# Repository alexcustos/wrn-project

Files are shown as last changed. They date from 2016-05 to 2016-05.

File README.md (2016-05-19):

# WRN Project

WRN is 3-in-1 device for RS232 serial port was designed to solve some standard problems of a home server.

## The board based on the ATmega328P and consist of:

* The hardware watchdog timer
* True random number generator (based on avalanche noise)
* Low power 2.4GHz transceiver (nRF24L01+)

## The project consist of the following components:

* The schematic and the PCB (KiCAD project)
* The firmware (AtmelStudio project)
* Linux daemon, watchdog driver and the installation for the Gentoo (Makefile)

The project depends on:
* [alexcustos/RF24](https://github.com/alexcustos/RF24)
* [alexcustos/RF24Network](https://github.com/alexcustos/RF24Network)

Here's an article in russian with more details:
* [Part 1](https://geektimes.ru/post/275912/)
* [Part 2](https://habrahabr.ru/post/300968/)

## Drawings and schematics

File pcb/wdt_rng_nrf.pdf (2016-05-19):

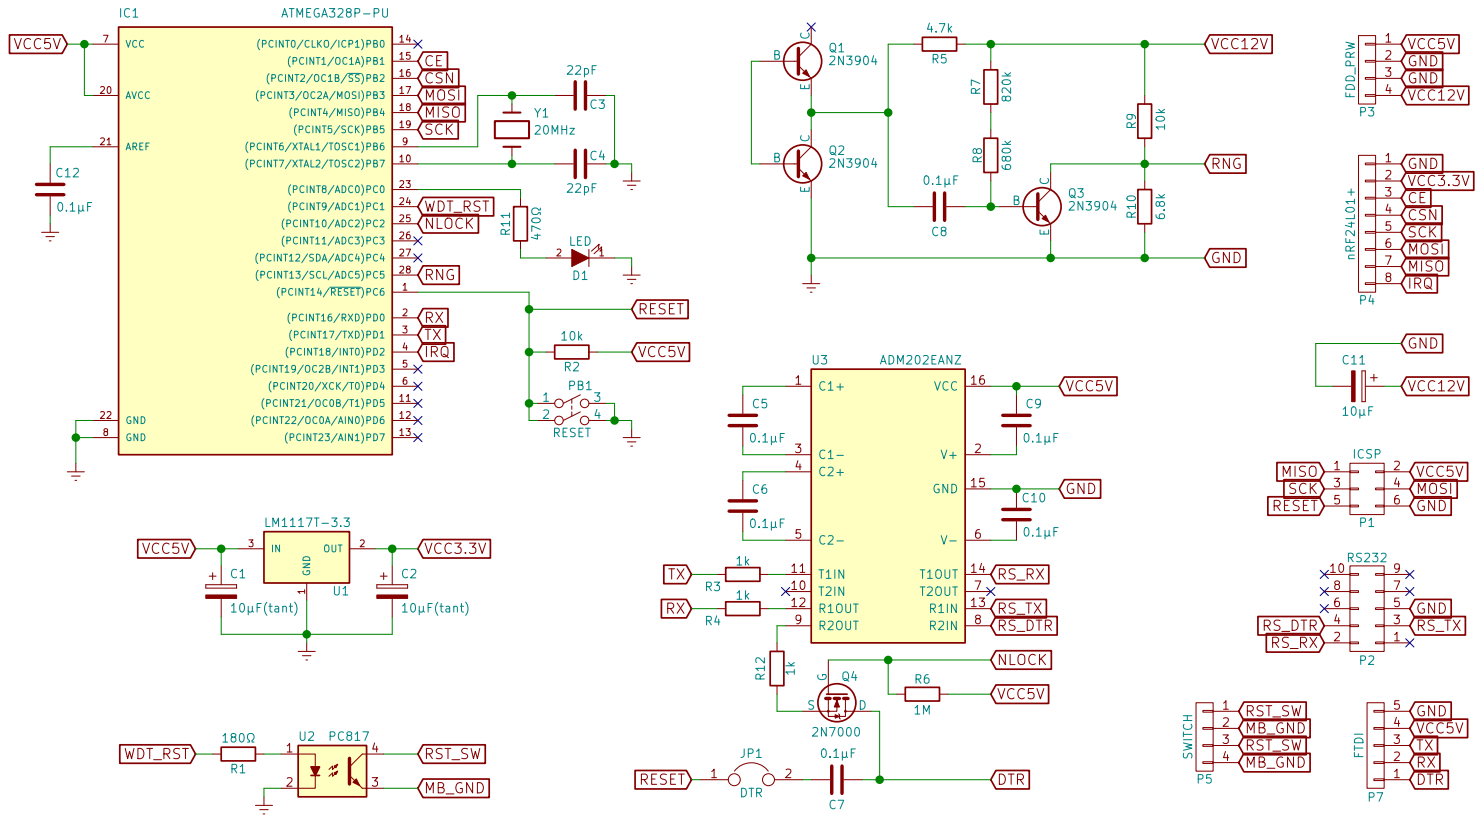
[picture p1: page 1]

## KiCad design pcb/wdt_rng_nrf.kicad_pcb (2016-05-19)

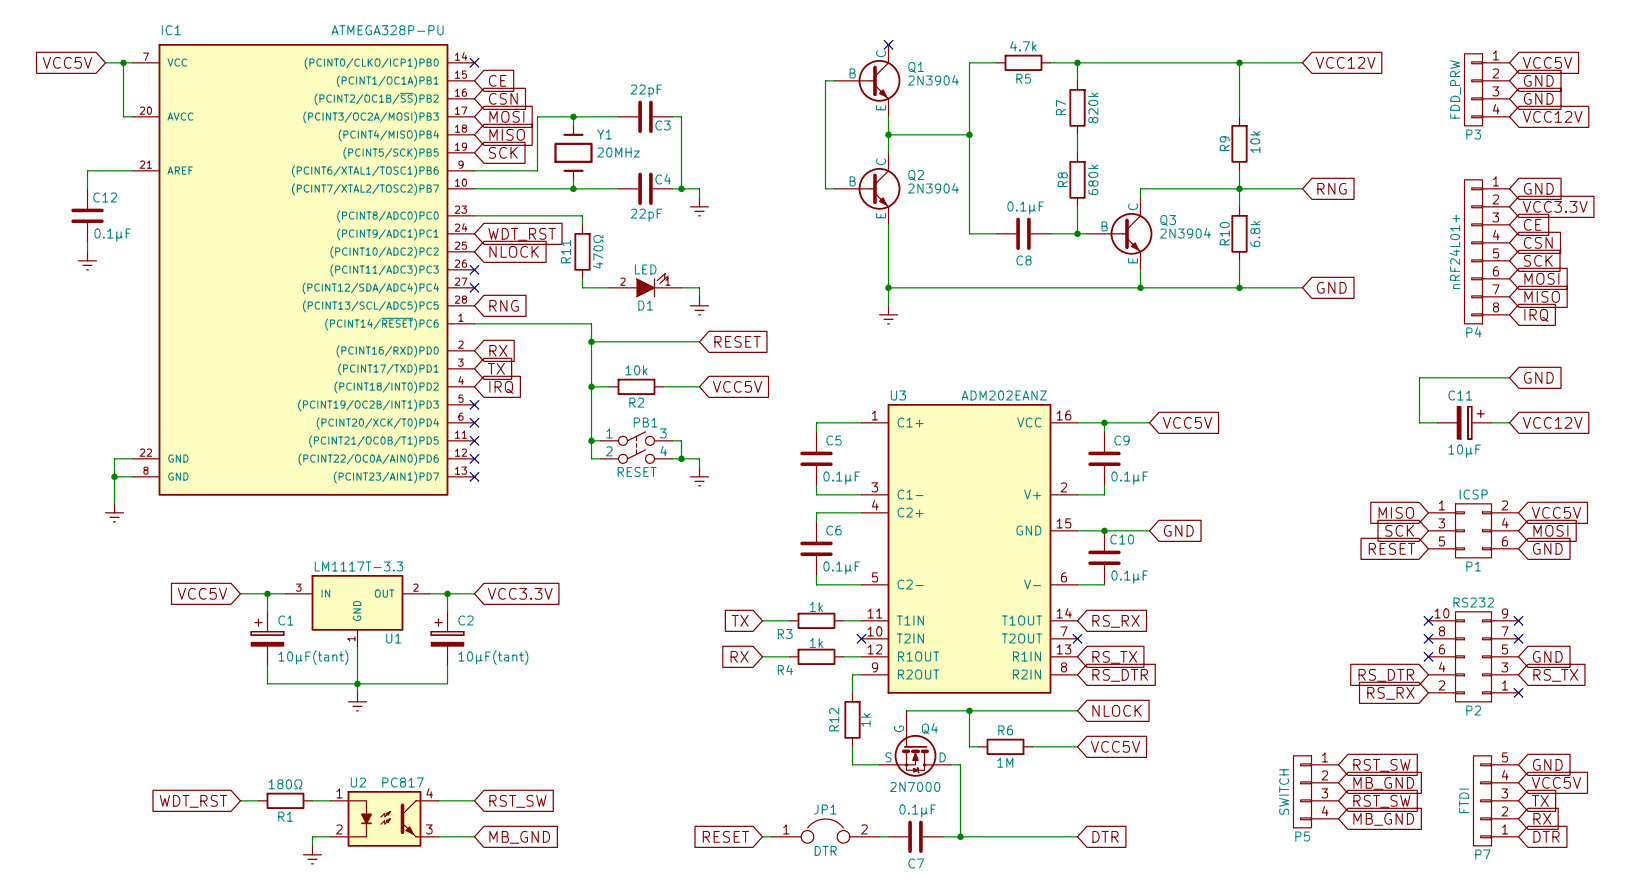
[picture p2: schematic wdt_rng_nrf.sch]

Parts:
C1, C2: 10μF(tant); C_Disc_D7.5_P5
C3, C4: 22pF; C_Disc_D3_P2.5
C5, C6, C7, C8, C9, C10, C12: 0.1μF; C_Disc_D7.5_P5
C11: 10μF; C_Radial_D5_L6_P2.5
D1: LED; LED-5MM
IC1: ATMEGA328P-PU; DIP-28_W7.62mm
JP1: DTR; Pin_Header_Straight_1x02
P1: ICSP; Pin_Header_Straight_2x03
P2: RS232; Pin_Header_Straight_2x05
P3: FDD_PRW; Pin_Header_Angled_1x04
P4: nRF24L01+; Pin_Header_Angled_1x08
P5: SWITCH; Pin_Header_Angled_1x04
P7: FTDI; Pin_Header_Straight_1x05
PB1: RESET; Push_E-Switch_TC-0102
Q1, Q2, Q3: 2N3904; TO-92_2N3904
Q4: 2N7000; TO-92_2N7000
R1: 180Ω; Resistor_Horizontal_RM10mm
R2, R9: 10k; Resistor_Horizontal_RM10mm
R3, R4, R12: 1k; Resistor_Horizontal_RM10mm
R5: 4.7k; Resistor_Horizontal_RM10mm
R6: 1M; Resistor_Horizontal_RM10mm
R7: 820k; Resistor_Horizontal_RM10mm
R8: 680k; Resistor_Horizontal_RM10mm
R10: 6.8k; Resistor_Horizontal_RM10mm
R11: 470Ω; Resistor_Horizontal_RM10mm
U1: LM1117T-3.3; TO-220_Neutral123_Horizontal
U2: PC817; DIP-4_W7.62mm
U3: ADM202EANZ; DIP-16_W7.62mm
Y1: 20MHz; Crystal_HC49-U_Vertical

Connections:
CE: IC1.15 ((PCINT1/OC1A)PB1), P4.3
CSN: IC1.16 ((PCINT2/OC1B/~SS~)PB2), P4.4
DTR: C7.1, P7.1, Q4.1 (D)
GND: C1.2, C2.2, C3.2, C4.2, C10.2, C11.2, C12.1, D1.1 (K), IC1.8 (GND), IC1.22 (GND), P1.6, P2.5, P3.2, P3.3, P4.1, P7.5, PB1.3, PB1.4, Q2.3 (E), Q3.3 (E), R10.1, U1.1 (GND), U2.2, U3.15 (GND)
IRQ: IC1.4 ((PCINT18/INT0)PD2), P4.8
MB_GND: P5.2, P5.4, U2.3
MISO: IC1.18 ((PCINT4/MISO)PB4), P1.1, P4.7
MOSI: IC1.17 ((PCINT3/OC2A/MOSI)PB3), P1.4, P4.6
NLOCK: IC1.25 ((PCINT10/ADC2)PC2), Q4.2 (G), R6.1
unnamed: C3.1, IC1.9 ((PCINT6/XTAL1/TOSC1)PB6), Y1.2
unnamed: C4.1, IC1.10 ((PCINT7/XTAL2/TOSC2)PB7), Y1.1
unnamed: C5.1, U3.3 (C1-)
unnamed: C5.2, U3.1 (C1+)
unnamed: C6.1, U3.5 (C2-)
unnamed: C6.2, U3.4 (C2+)
unnamed: C7.2, JP1.2
unnamed: C8.1, Q3.2 (B), R8.1
unnamed: C8.2, Q1.3 (E), Q2.1 (C), R5.2
unnamed: C9.1, U3.2 (V+)
unnamed: C10.1, U3.6 (V-)
unnamed: C12.2, IC1.21 (AREF)
unnamed: D1.2 (A), R11.1
unnamed: IC1.23 ((PCINT8/ADC0)PC0), R11.2
unnamed: Q1.2 (B), Q2.2 (B)
unnamed: Q4.3 (S), R12.1
unnamed: R1.1, U2.1
unnamed: R3.1, U3.11 (T1IN)
unnamed: R4.1, U3.12 (R1OUT)
unnamed: R7.1, R8.2
unnamed: R12.2, U3.9 (R2OUT)
RESET: IC1.1 ((PCINT14/~RESET~)PC6), JP1.1, P1.5, PB1.1, PB1.2, R2.2
RNG: IC1.28 ((PCINT13/SCL/ADC5)PC5), Q3.1 (C), R9.1, R10.2
RST_SW: P5.1, P5.3, U2.4
RS_DTR: P2.4, U3.8 (R2IN)
RS_RX: P2.2, U3.14 (T1OUT)
RS_TX: P2.3, U3.13 (R1IN)
RX: IC1.2 ((PCINT16/RXD)PD0), P7.2, R4.2
SCK: IC1.19 ((PCINT5/SCK)PB5), P1.3, P4.5
TX: IC1.3 ((PCINT17/TXD)PD1), P7.3, R3.2
VCC3.3V: C2.1, P4.2, U1.2 (OUT)
VCC5V: C1.1, C9.2, IC1.7 (VCC), IC1.20 (AVCC), P1.2, P3.1, P7.4, R2.1, R6.2, U1.3 (IN), U3.16 (VCC)
VCC12V: C11.1, P3.4, R5.1, R7.2, R9.2
WDT_RST: IC1.24 ((PCINT9/ADC1)PC1), R1.2

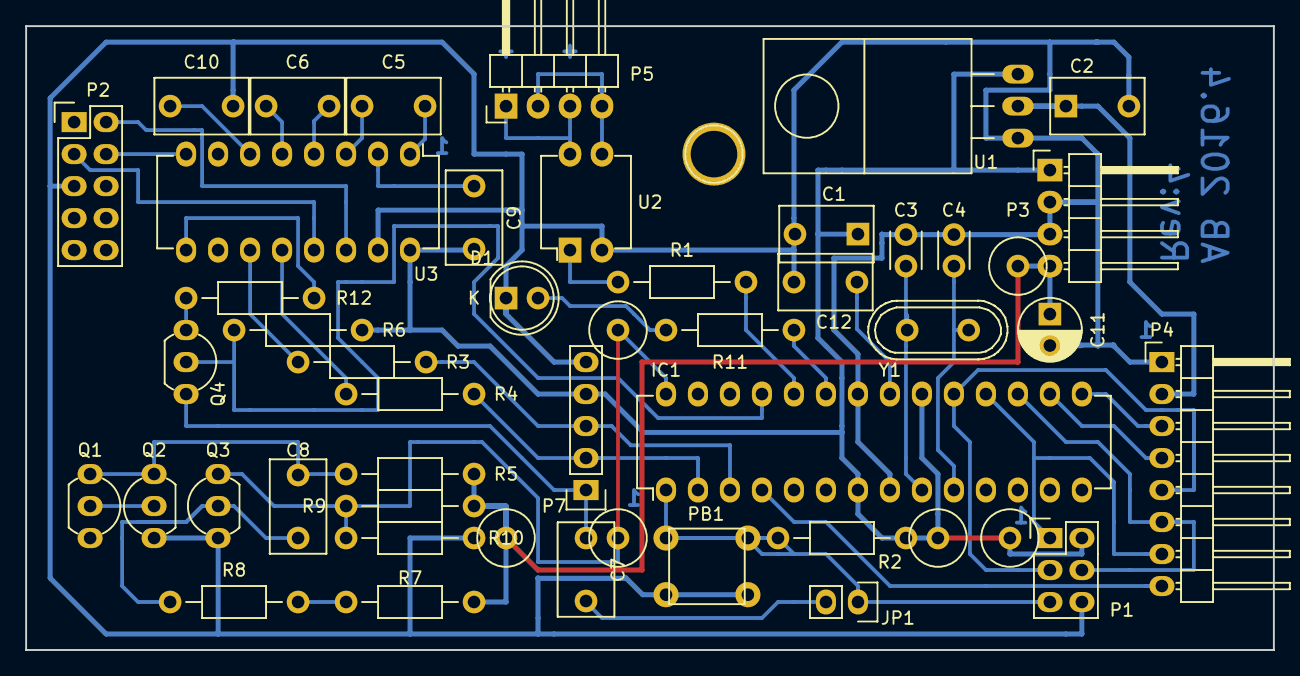
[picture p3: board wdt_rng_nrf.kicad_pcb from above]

Board: 2 copper layers, 99.1 x 49.5 mm, 42 parts (0 on the bottom side), 43 nets.

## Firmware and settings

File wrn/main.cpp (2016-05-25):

// Copyright (c) 2016 Aleksandr Borisenko
// Distributed under the terms of the GNU General Public License v2

#define DEBUG_CMD_DELAY 1000
#define RF24_CHANEL 62 // uint8_t
#define WDT_BITS_PER_CYCLE 16


#include <avr/io.h>
#include <avr/wdt.h>
#include <stdio.h>
#include <util/delay.h>
#include <inttypes.h>
#include <string.h>
#include "HardwareSerial.h"
#include "Time.h"
#include "SerialCommand.h"
#include "Devices.h"
#include "WDTDevice.h"
#include "RNGDevice.h"
#include "SPI.h"
#include <RF24Network.h>
#include <RF24.h>
#include "EepromLog.h"
#include "main.h"

SerialCommand cmd(&sys_serial);
CommonDevice common_device;
WDTDevice wdt_device;
RNGDevice rng_device;
NRFDevice nrf_device;

// const uint16_t sensor_node = 1;
const uint16_t rx_node = 0;

RF24 radio;
RF24Network network(&radio);

int serial_putc(char c, FILE *)
{
	// 0 - if the output was successful, and a nonzero value if the character could not be sent
	return (sys_serial.write(c) != 1);
}

void blink_once(void)
{
	PORTC |= _BV(PORTC0);
	_delay_ms(10);
	PORTC &= ~_BV(PORTC0);
}

int main(void)
{
	bool cmd_ok = false;

	wdt_enable(WDTO_8S);

	// ADC enable; prescaler: 128 (156 KHz @ 20MHz)
	ADCSRA |= (_BV(ADEN) | _BV(ADPS2) | _BV(ADPS1) | _BV(ADPS0));
	DDRC |= _BV(DDC0);  // LED:OUTPUT

	// NLOCK: locked
	DDRC |= _BV(DDC2);  // OUTPUT
	PORTC &= ~_BV(PORTC2);  // LOW

#ifdef DEBUG
	int m = DEBUG_CMD_DELAY;  // ms
	fdevopen(&serial_putc, 0);  // open the stdout and stderr streams
#endif

	sys_serial.begin(57600);
	IF_DEBUG(printf_P(PSTR("BOOT\r\n")));

	// initiate a sync with the daemon after boot
	// there is a 1:65536 chance that sync will not be lost
	// the daemon will initialize the device by the command
	cmd.set(CMD_COMMON, COMMON_RESET, 0, 0);
	common_device.confirm_boot(&cmd);
	//cmd.reset();  // look to the SerialCommand::read

	sys_log.begin();
	SPI.begin();
	if (radio.begin()) {
		 network.begin(RF24_CHANEL, rx_node);
		 nrf_device.setup(&network);
	}

	while(true)
	{
		wdt_reset();

		// CMD_NRF_FORWARD
		if (nrf_device.read(&cmd)) {
			if (!nrf_device.run(&cmd)) cmd.send_header(-1);
			//cmd.reset();
		}

		// CMD_RNG_SEND
		for (int i = 0; i < WDT_BITS_PER_CYCLE; i++) {
			if (rng_device.read(&cmd)) {
				if (!rng_device.run(&cmd)) cmd.send_header(-1);
				//cmd.reset();
			}
		}

		// watchdog trigger
		wdt_device.update();

#ifdef DEBUG
		if (--m <= 0) {
			m = DEBUG_CMD_DELAY;
			//cmd.set(CMD_COMMON, 1, 1460792071, 0); // look to the SerialCommand::read
			//sys_log.write(sys_time.now(), LOG_BOOT);
		}
		//_delay_ms(1);
#endif

		// serial commands
		if (cmd.read()) {
#ifdef DEBUG
			blink_once();
#endif
			cmd_ok = false;
			switch (cmd.get_type()) {
				case CMD_COMMON:
					cmd_ok = common_device.run(&cmd);
					break;
				case CMD_WDT:
					cmd_ok = wdt_device.run(&cmd);
					break;
				case CMD_RNG:
					cmd_ok = rng_device.run(&cmd);
					break;
				case CMD_NRF:
					cmd_ok = nrf_device.run(&cmd);
					break;
				default:
					break;
			}
			if (!cmd_ok) cmd.send_header(-1);
			//cmd.reset();
		}
	} // while(true)

	sys_serial.end();
	return 0;
} // main

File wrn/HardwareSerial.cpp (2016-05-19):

/*
  HardwareSerial.cpp - Hardware serial library for Wiring
  Copyright (c) 2006 Nicholas Zambetti.  All right reserved.

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
  Modified 23 November 2006 by David A. Mellis
  Modified 28 September 2010 by Mark Sproul
  Modified 14 August 2012 by Alarus
  Modified 3 December 2013 by Matthijs Kooijman
  Modified 26 April 2016 by Aleksandr Borisenko to make it compile without arduino core.
*/

#include <avr/io.h>
#include <inttypes.h>
#include <avr/interrupt.h>
#include "HardwareSerial.h"

HardwareSerial::HardwareSerial() : _written(false), _rx_buffer_head(0), _rx_buffer_tail(0), _tx_buffer_head(0), _tx_buffer_tail(0)
{
}

void HardwareSerial::begin(unsigned long baud)
{
	uint16_t baud_setting = F_CPU / 8 / baud - 1;

	// UBRR 12-bit register
	if (baud_setting > 4095) {
		// USART Control and Status Register A
		UCSR0A = 0;
		baud_setting = F_CPU / 16 / baud - 1;
	} else {
		UCSR0A = _BV(U2X0);
	}

	// USART Baud Rate Registers
	UBRR0H = baud_setting >> 8;
	UBRR0L = baud_setting;

	// Asynchronous USART; Parity Disabled; 1-Stop Bit; 8-bit Character Size
	UCSR0C = _BV(UCSZ01) | _BV(UCSZ00);

	// Receiver Enable; Transmitter Enable
	UCSR0B = _BV(RXEN0) | _BV(TXEN0);

	cli();
	// RX Complete Interrupt Enable
	UCSR0B |= _BV(RXCIE0);
	sei();

	_written = false;
}

void HardwareSerial::end(void)
{
	flush();
	UCSR0B = 0; // Initial Value
	_rx_buffer_head = _rx_buffer_tail;
}

void HardwareSerial::flush()
{
	// No way to force the TXC (transmit complete) bit to 1 during initialization
	if (!_written) return;

	// UDRIE0 - USART Data Register Empty Interrupt Enable
	// TXC0 - USART Transmit Complete
	// UDRE0 - USART Data Register Empty
	while (bit_is_set(UCSR0B, UDRIE0) || bit_is_clear(UCSR0A, TXC0)) {
		if (bit_is_clear(SREG, SREG_I) && bit_is_set(UCSR0B, UDRIE0)) {
			// Interrupts are globally disabled, so poll the DR empty flag
			if (bit_is_set(UCSR0A, UDRE0)) _tx_udr_empty_irq();
		}
	}
}

HardwareSerial sys_serial;

ISR(USART_RX_vect)
{
	sys_serial._rx_complete_irq();
}

ISR(USART_UDRE_vect)
{
	sys_serial._tx_udr_empty_irq();
}

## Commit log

2016-05-19 Release v0.1
    [wdt_rng_nrf.kicad_pcb, wdt_rng_nrf.sch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]
2016-05-20 Added: WDT fifo to make the driver useless
